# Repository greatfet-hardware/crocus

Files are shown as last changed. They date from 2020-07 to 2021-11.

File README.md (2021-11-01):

# Crocus
A GreatFET Neighbor for the 2.4 GHz wireless band.

Required KiCad dependency:

https://github.com/greatscottgadgets/gsg-kicad-lib

If you are using git, the preferred way to install gsg-kicad-lib is to use the
submodule:

```
git submodule init && git submodule update
```

# Background

Crocus is based on the Nordic RF nRF24L01+ and was inspired by [The Next Hope Badge](http://goodfet.sourceforge.net/hardware/nhb12/).

A notable capability of nRF24L01+ is 2 Mbps FSK.  Many 2.4 GHz wireless transceiver ICs (including the CC2400 on Ubertooth One) only support FSK up to 1 Mbps.  See [Promiscuity is the nRF24L01+'s Duty](http://travisgoodspeed.blogspot.com/2011/02/promiscuity-is-nrf24l01s-duty.html) for an excellent trick that can be done with Crocus.

## Usage Instructions

FIXME: We don't have any firmware yet, but we should implement capabilities similar to goodfet.nrf.

## Pin Usage

signal  | pin     | alt1  | alt2
--------|---------|-------|-----
SCK     | J1.38   | J2.32 |
COPI    | J1.39   | J2.30 |
CIPO    | J1.40   | J2.38 |
CSN     | via I2C | J1.37 | J1.29
CE      | via I2C | J2.9  | J2.21
SDA     | J2.39   |       |
SCL     | J2.40   |       |
INT     | J2.4    | J2.34 | J1.36

Alternative pins may be selected with solder jumpers.

## I2C Address

The default I2C address is 0x27.  Alternative addresses in the ranges 0x10-0x2F, 0x50-0x67, or 0x70-0x77 may be selected with solder jumpers.  Refer to the Crocus schematic and to the PCA9674 data sheet for details.

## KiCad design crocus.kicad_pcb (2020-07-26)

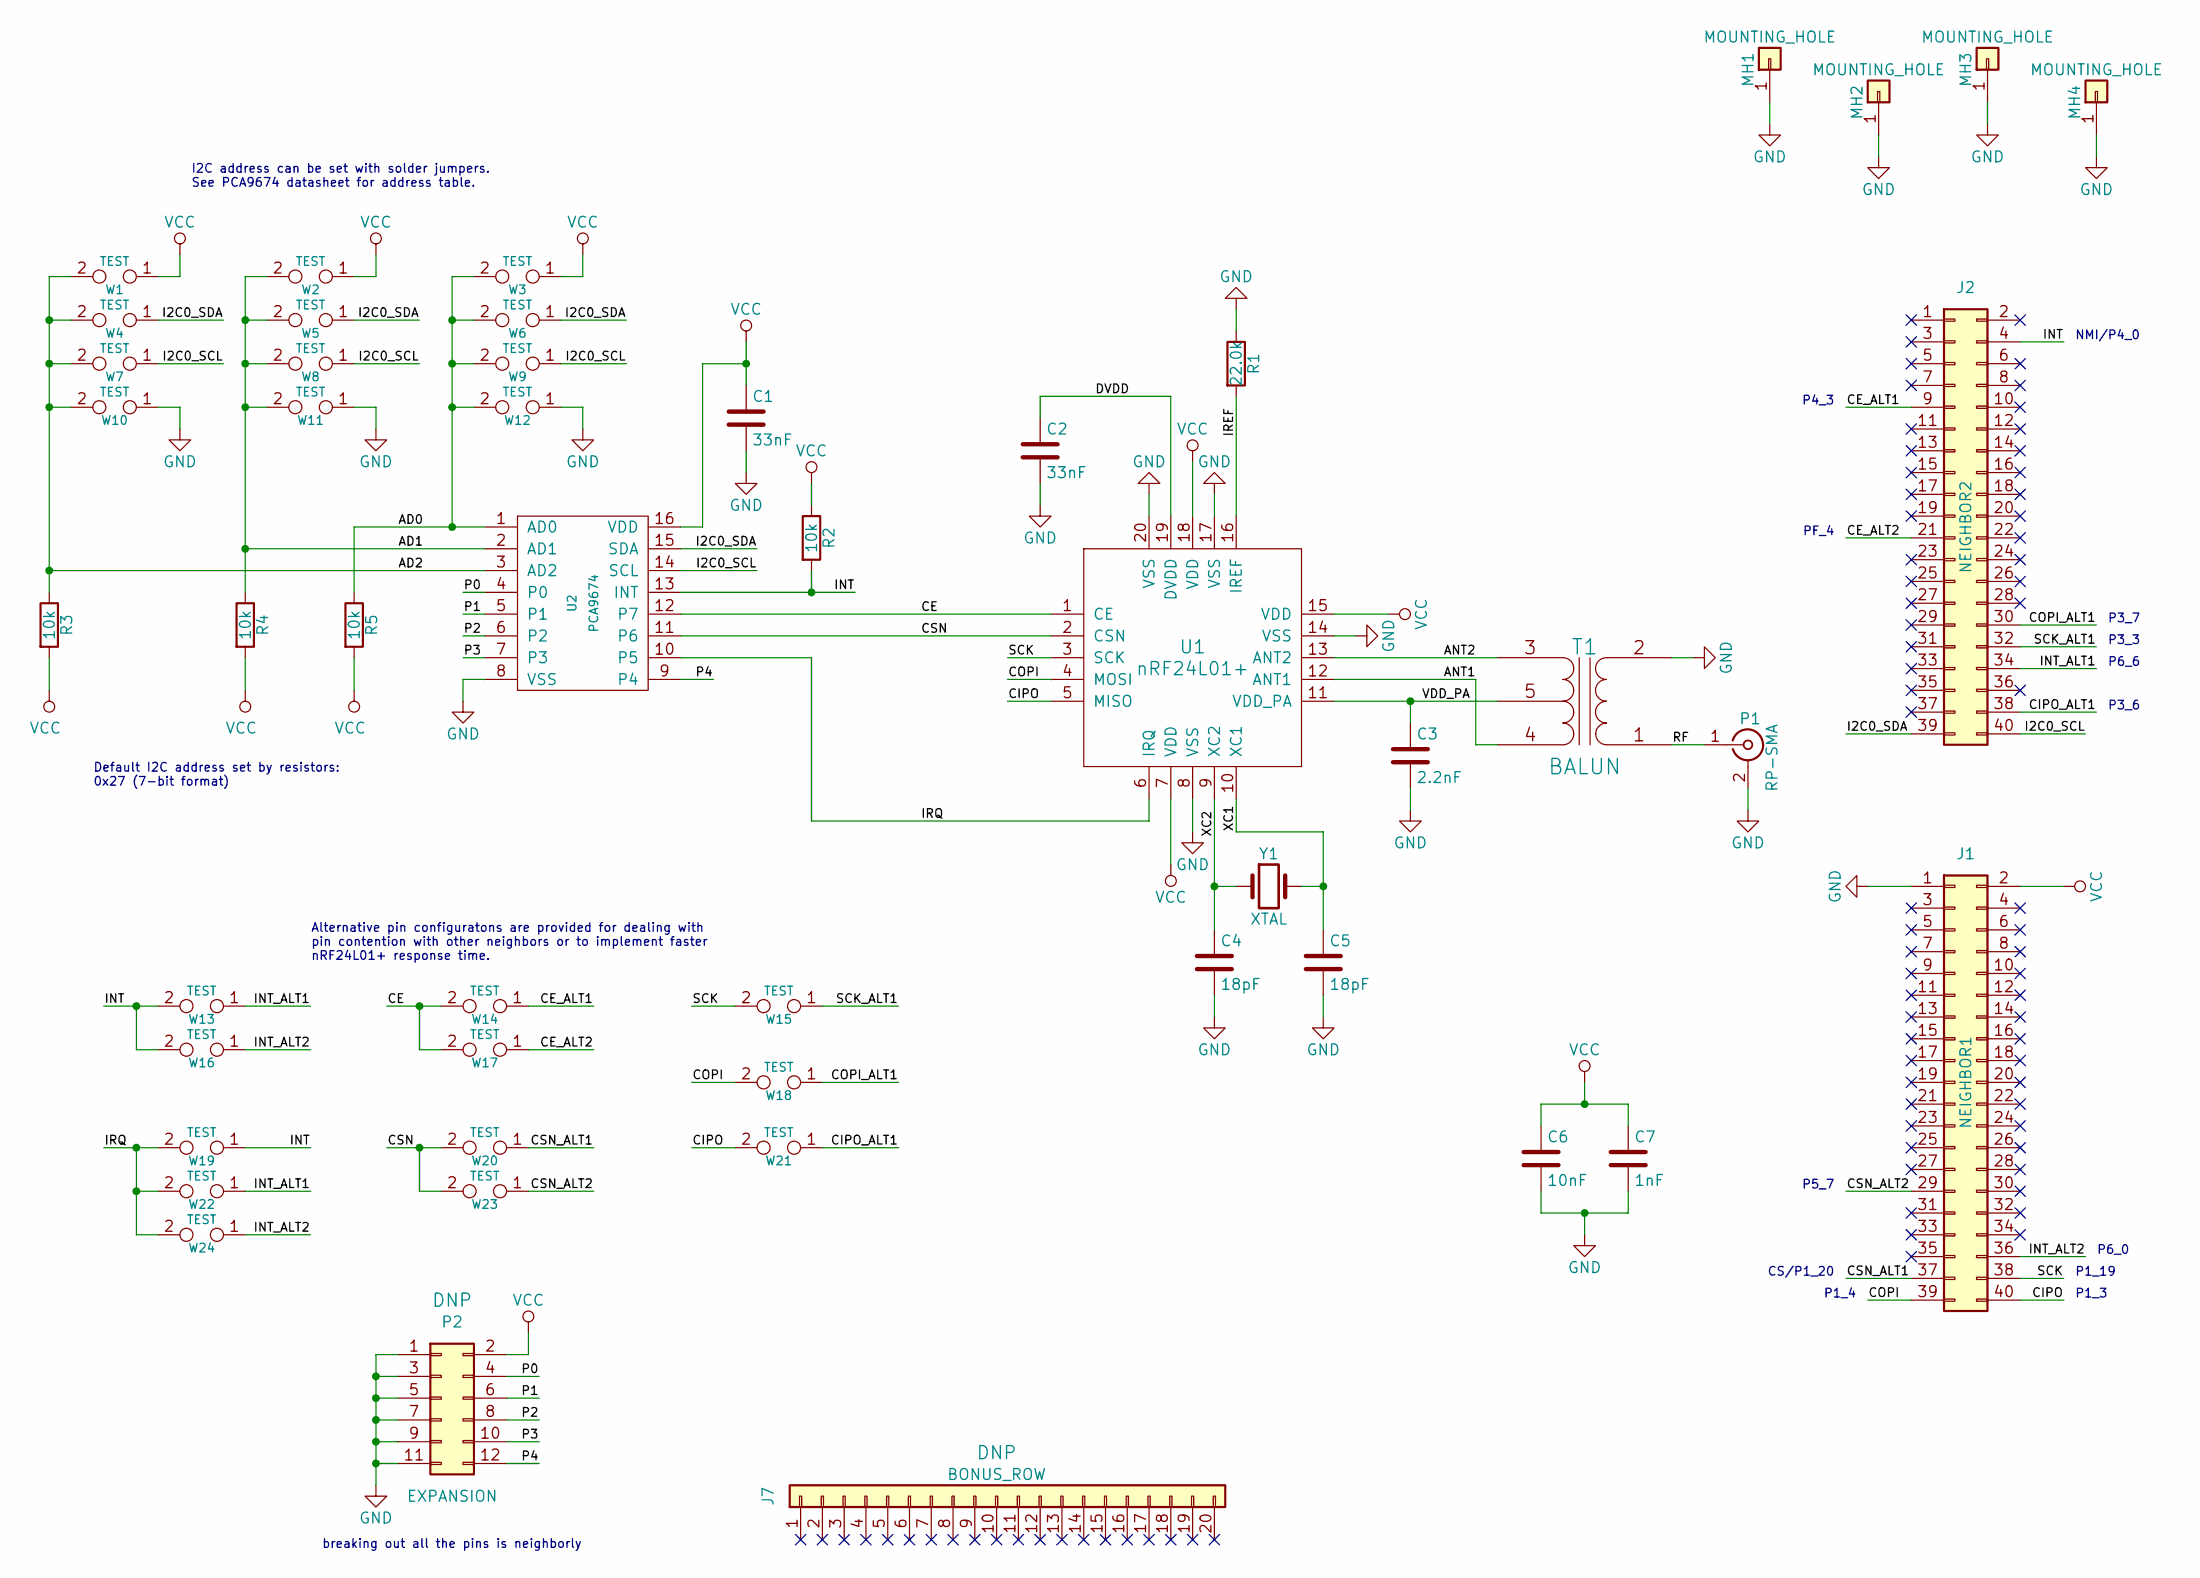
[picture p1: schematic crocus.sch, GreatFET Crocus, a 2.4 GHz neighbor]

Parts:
C1, C2: 33nF; 0603; Part Number CL10B333KB8SFNC
C3: 2.2nF; 0603; Part Number GRM188R71H222KA01D
C4, C5: 18pF; 0603; Part Number GRM1885C1H180JA01D
C6: 10nF; 0603; Part Number GRM188R71H103KA01D
C7: 1nF; 0603; Part Number GRM188R71H102KA01D
J1: NEIGHBOR1; HEADER-2x20; Part Number SSQ-120-23-G-D
J2: NEIGHBOR2; HEADER-2x20; Part Number SSQ-120-23-G-D
J7: BONUS_ROW; HEADER-1x20; Part Number SSQ-120-23-G-S
MH1, MH2, MH3, MH4: MOUNTING_HOLE; HOLE126MIL-COPPER
P1: RP-SMA; SMA-EDGE; Part Number CONREVSMA003.031
P2: EXPANSION; HEADER-2x6
R1: 22.0k; 0603; Part Number RMCF0603FT22K0
R2, R3, R4, R5: 10k; 0603; Part Number ERJ-3GEYJ103V
T1: BALUN; 2500BL14M100; Part Number 2450BM14A0002T
U1: nRF24L01+; QFN20-4; Part Number NRF24L01P-R7
U2: PCA9674; TSSOP16; Part Number PCA9674PW,118
W1, W2, W3, W4, W5, W6, W7, W8, W9, W10, W11, W12, W13, W14, W15, W16, W17, W18, W19, W20, W21, W22, W23, W24: TEST; 0603-JUMPER
Y1: XTAL; HC-49S; Part Number 9C-16.000MAAE-T

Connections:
/AD0: R5.1, U2.1 (AD0), W3.2, W6.2, W9.2, W12.2
/AD1: R4.1, U2.2 (AD1), W2.2, W5.2, W8.2, W11.2
/AD2: R3.1, U2.3 (AD2), W1.2, W4.2, W7.2, W10.2
/ANT1: T1.4 (PR2), U1.12 (ANT1)
/ANT2: T1.3 (PR1), U1.13 (ANT2)
/CE: U1.1 (CE), U2.12 (P7), W14.2, W17.2
/CE_ALT1: J2.9, W14.1
/CE_ALT2: J2.21, W17.1
/CIPO: J1.40, U1.5 (MISO), W21.2
/CIPO_ALT1: J2.38, W21.1
/COPI: J1.39, U1.4 (MOSI), W18.2
/COPI_ALT1: J2.30, W18.1
/CSN: U1.2 (CSN), U2.11 (P6), W20.2, W23.2
/CSN_ALT1: J1.37, W20.1
/CSN_ALT2: J1.29, W23.1
/DVDD: C2.1, U1.19 (DVDD)
/I2C0_SCL: J2.40, U2.14 (SCL), W7.1, W8.1, W9.1
/I2C0_SDA: J2.39, U2.15 (SDA), W4.1, W5.1, W6.1
/INT: J2.4, R2.2, U2.13 (INT), W13.2, W16.2, W19.1
/INT_ALT1: J2.34, W13.1, W22.1
/INT_ALT2: J1.36, W16.1, W24.1
/IREF: R1.2, U1.16 (IREF)
/IRQ: U1.6 (IRQ), U2.10 (P5), W19.2, W22.2, W24.2
/P0: P2.4, U2.4 (P0)
/P1: P2.6, U2.5 (P1)
/P2: P2.8, U2.6 (P2)
/P3: P2.10, U2.7 (P3)
/P4: P2.12, U2.9 (P4)
/RF: P1.1 (In), T1.1 (S1)
/SCK: J1.38, U1.3 (SCK), W15.2
/SCK_ALT1: J2.32, W15.1
/VDD_PA: C3.1, T1.5 (PM), U1.11 (VDD_PA)
/XC1: C5.1, U1.10 (XC1), Y1.2
/XC2: C4.1, U1.9 (XC2), Y1.1

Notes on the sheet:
P1_3
P1_4
P1_19
CS/P1_20
breaking out all the pins is neighborly
I2C address can be set with solder jumpers. See PCA9674 datasheet for address table.
Default I2C address set by resistors: 0x27 (7-bit format)
NMI/P4_0
P6_0
P3_3
P3_7
P3_6
P6_6
P4_3
PF_4
P5_7
Alternative pin configuratons are provided for dealing with pin contention with other neighbors or to implement faster nRF24L01+ response time.

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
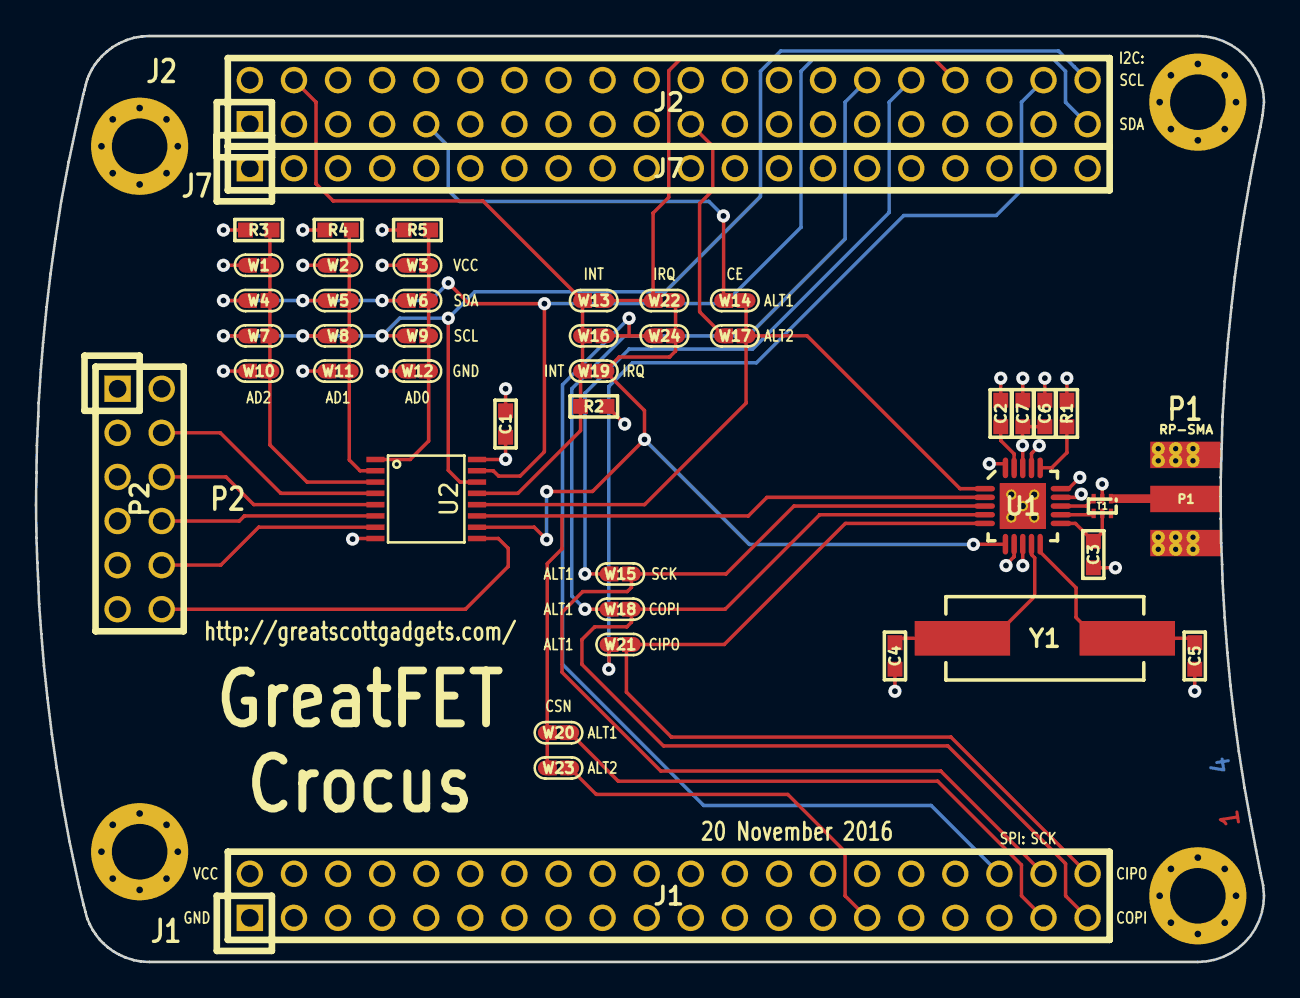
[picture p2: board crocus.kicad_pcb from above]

Board: 4 copper layers, 70.7 x 53.3 mm, 49 parts (0 on the bottom side), 36 nets.

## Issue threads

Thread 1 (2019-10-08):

I2C address conflict

mossmann, 2019-10-08:
Jasmine is using 0x20 and only has one address pin. Change address on Crocus to avoid conflict.

https://github.com/greatscottgadgets/greatfet/wiki/I2C-Registry

mossmann, 2019-10-09:
Also update the I2C registry.

straithe, 2021-11-01:
@yhetti, @mossmann  was this issue solved with the merged pull request that was mentioned?

yhetti, 2021-11-01:
I believe that is correct. I have changed the README to reflect this change as well.

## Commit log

2019-05-27 split crocus into separate repository
    [azalea.kicad_pcb, azalea.sch, begonia.kicad_pcb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]
2019-10-10 Updated design for kicad 5.
    [crocus.sch]
2019-10-10 Changed I2C address to 0x27
    [crocus.sch]
2020-07-03 adopt OSHWA convention for SPI signal names https://www.oshwa.org/a-resolution-to-redefine-spi-signal-names
    [crocus.kicad_pcb, crocus.sch]
2021-11-01 Update README to reflect I2C address change.
    PR #2 changed the I2C address of Crocus from 0x20 to 0x27.

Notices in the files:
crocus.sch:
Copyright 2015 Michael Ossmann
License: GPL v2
